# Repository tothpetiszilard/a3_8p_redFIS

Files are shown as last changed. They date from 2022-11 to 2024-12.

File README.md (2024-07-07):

# Audi A3 8P Red FIS Project
<b>This is a project about discovering (reverse-engineering) Audi A3 8P dashboard's Driver Information System and its protocol.</b>

For people who don't know what is DIS or FIS:
https://www.youtube.com/watch?v=bKFak5AGAGo

The goal is to implement a similiar but simpler open-source alternative to the "FIS-Control" or "Polar FIS".<br>
https://fis-control.de/index_en.html<br>
https://www.urotuning.com/products/polar-fis-advanced-multi-function-display-pf-04?variant=8384889323575

<b> Picture about the current status:</b><br>
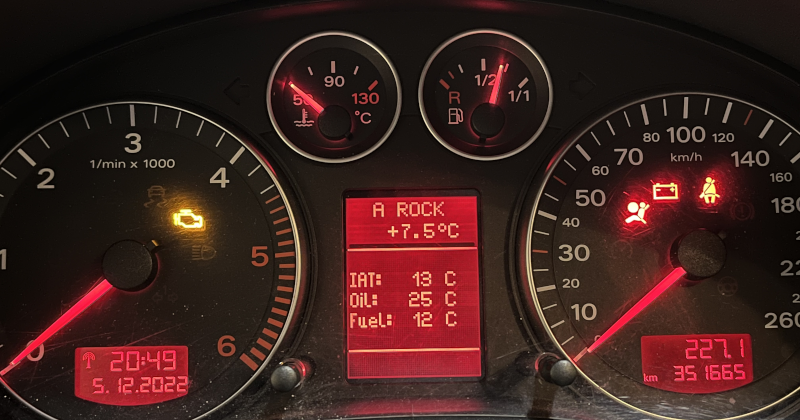
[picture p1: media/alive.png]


## Compatibility:
Selectable in "menuconfig":
- You can use Alternative VWTP CANID if you have RNS-E (Audi navigation with color display) installed and your dashboards part number is "8P0 920 930". Don't select "FIS-Control" in your RNS-E custom firmware in this case. Enter/exit FIS scenarios are a bit buggy.

- You have to use Navigation VWTP CANID if you have dashboard with part number "8P0 920 931". Alternative CANID is not supported by the dash. 

You may select "FIS-Control" in your RNS-E custom firmware in this case, and RedFIS will do the routing of the display data from RNS-E to the Dash - if that last "page" is selected using the Up/Down stalk buttons. This feature can be enabled (or disabled) in the menuconfig.
Default state is enabled, since my car has a navigation with custom firmware and "FIS-Control" option enabled.

<i>Brave volunteers are warmly welcomed for testing... :)</i>

Used and helpful sources:<br>
https://docs.google.com/spreadsheets/d/1eirT8LbSRl4j06BpwgsiE4PM_2BGH9UStdWLXwKvHJw/edit#gid=10<br>
https://i-wiki.tech/?post=vw-transport-protocol-20-tp-20-for-can-bus<br>
http://www.orlaus.dk/mercantec/UdvidetHardwareSoftware/Can/OBD2/VW%20Transport%20Protocol%202.0%20(TP%202.0)%20for%20CAN%20bus%20_%20jazdw.pdf<br>
https://github.com/openvehicles/Open-Vehicle-Monitoring-System-3/blob/master/vehicle/OVMS.V3/components/vehicle/docs/VW-TP-2.0.txt<br>

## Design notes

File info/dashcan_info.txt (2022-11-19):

CAN frames on the bus where the Dashboard is connected:

ID: 470 DLC: 5 [0][1][2][3][4]
byte 0: 128 = battery symbol shown
byte 1: doors: 1 = FL, 2 = FR,4= RL, 8 = RR, 16 = hood, 32 = trunk
byte 2: backlight dimming
byte 3: unknown
byte 4: 64 = light sensor error

ID: 1A0 DLC: 8 [0][1][2][3][4][5][6][7]
byte 1: errors, 1 = abs,2 = esp
byte 7: systick, 10ms increments

ID: 531 DLC: 4 [0][1][2][3]
byte 0: lamps: 4 = high beam
byte 1: symbols: 4 = green arrows
byte 2: turn signals: 1=left,2=right
byte 3: unknown

ID: 2A0 DLC: 8 [0][1][2][3][4][5][6][7]
byte 3: 1 = tire pressure monitoring error

ID: 3D0 DLC: 6 [0][1][2][3][4][5]
byte 1: 1 = steering error symbol

ID: 480 DLC: 8 [0][1][2][3][4][5][6][7]
byte 1: errors: 2=preglow,8=engine,16=coolant

ID: 280 DLC: 8 [0][1][rpm][rpm][4][5][6][7]
byte 2: LSB of engine speed?
byte 3: MSB of engine speed

ID: 661 DLC: 8 [FIS][?][?][?][?][?][?][?]
byte 0: FIS: 1 = ON

ID: 595 DLC: 3 [0][1][?] // trailer
byte 0: trailer light failures: brake=1,fog=2,reverse=4
byte 1: trailer light failures: right_turn=4,right_rear_light=8,left_turn=64,left_rear_light=128 

ID: 575 DLC:4 [ignition switch][1][2][3]
byte 0: ignition switch: 2 = KL15

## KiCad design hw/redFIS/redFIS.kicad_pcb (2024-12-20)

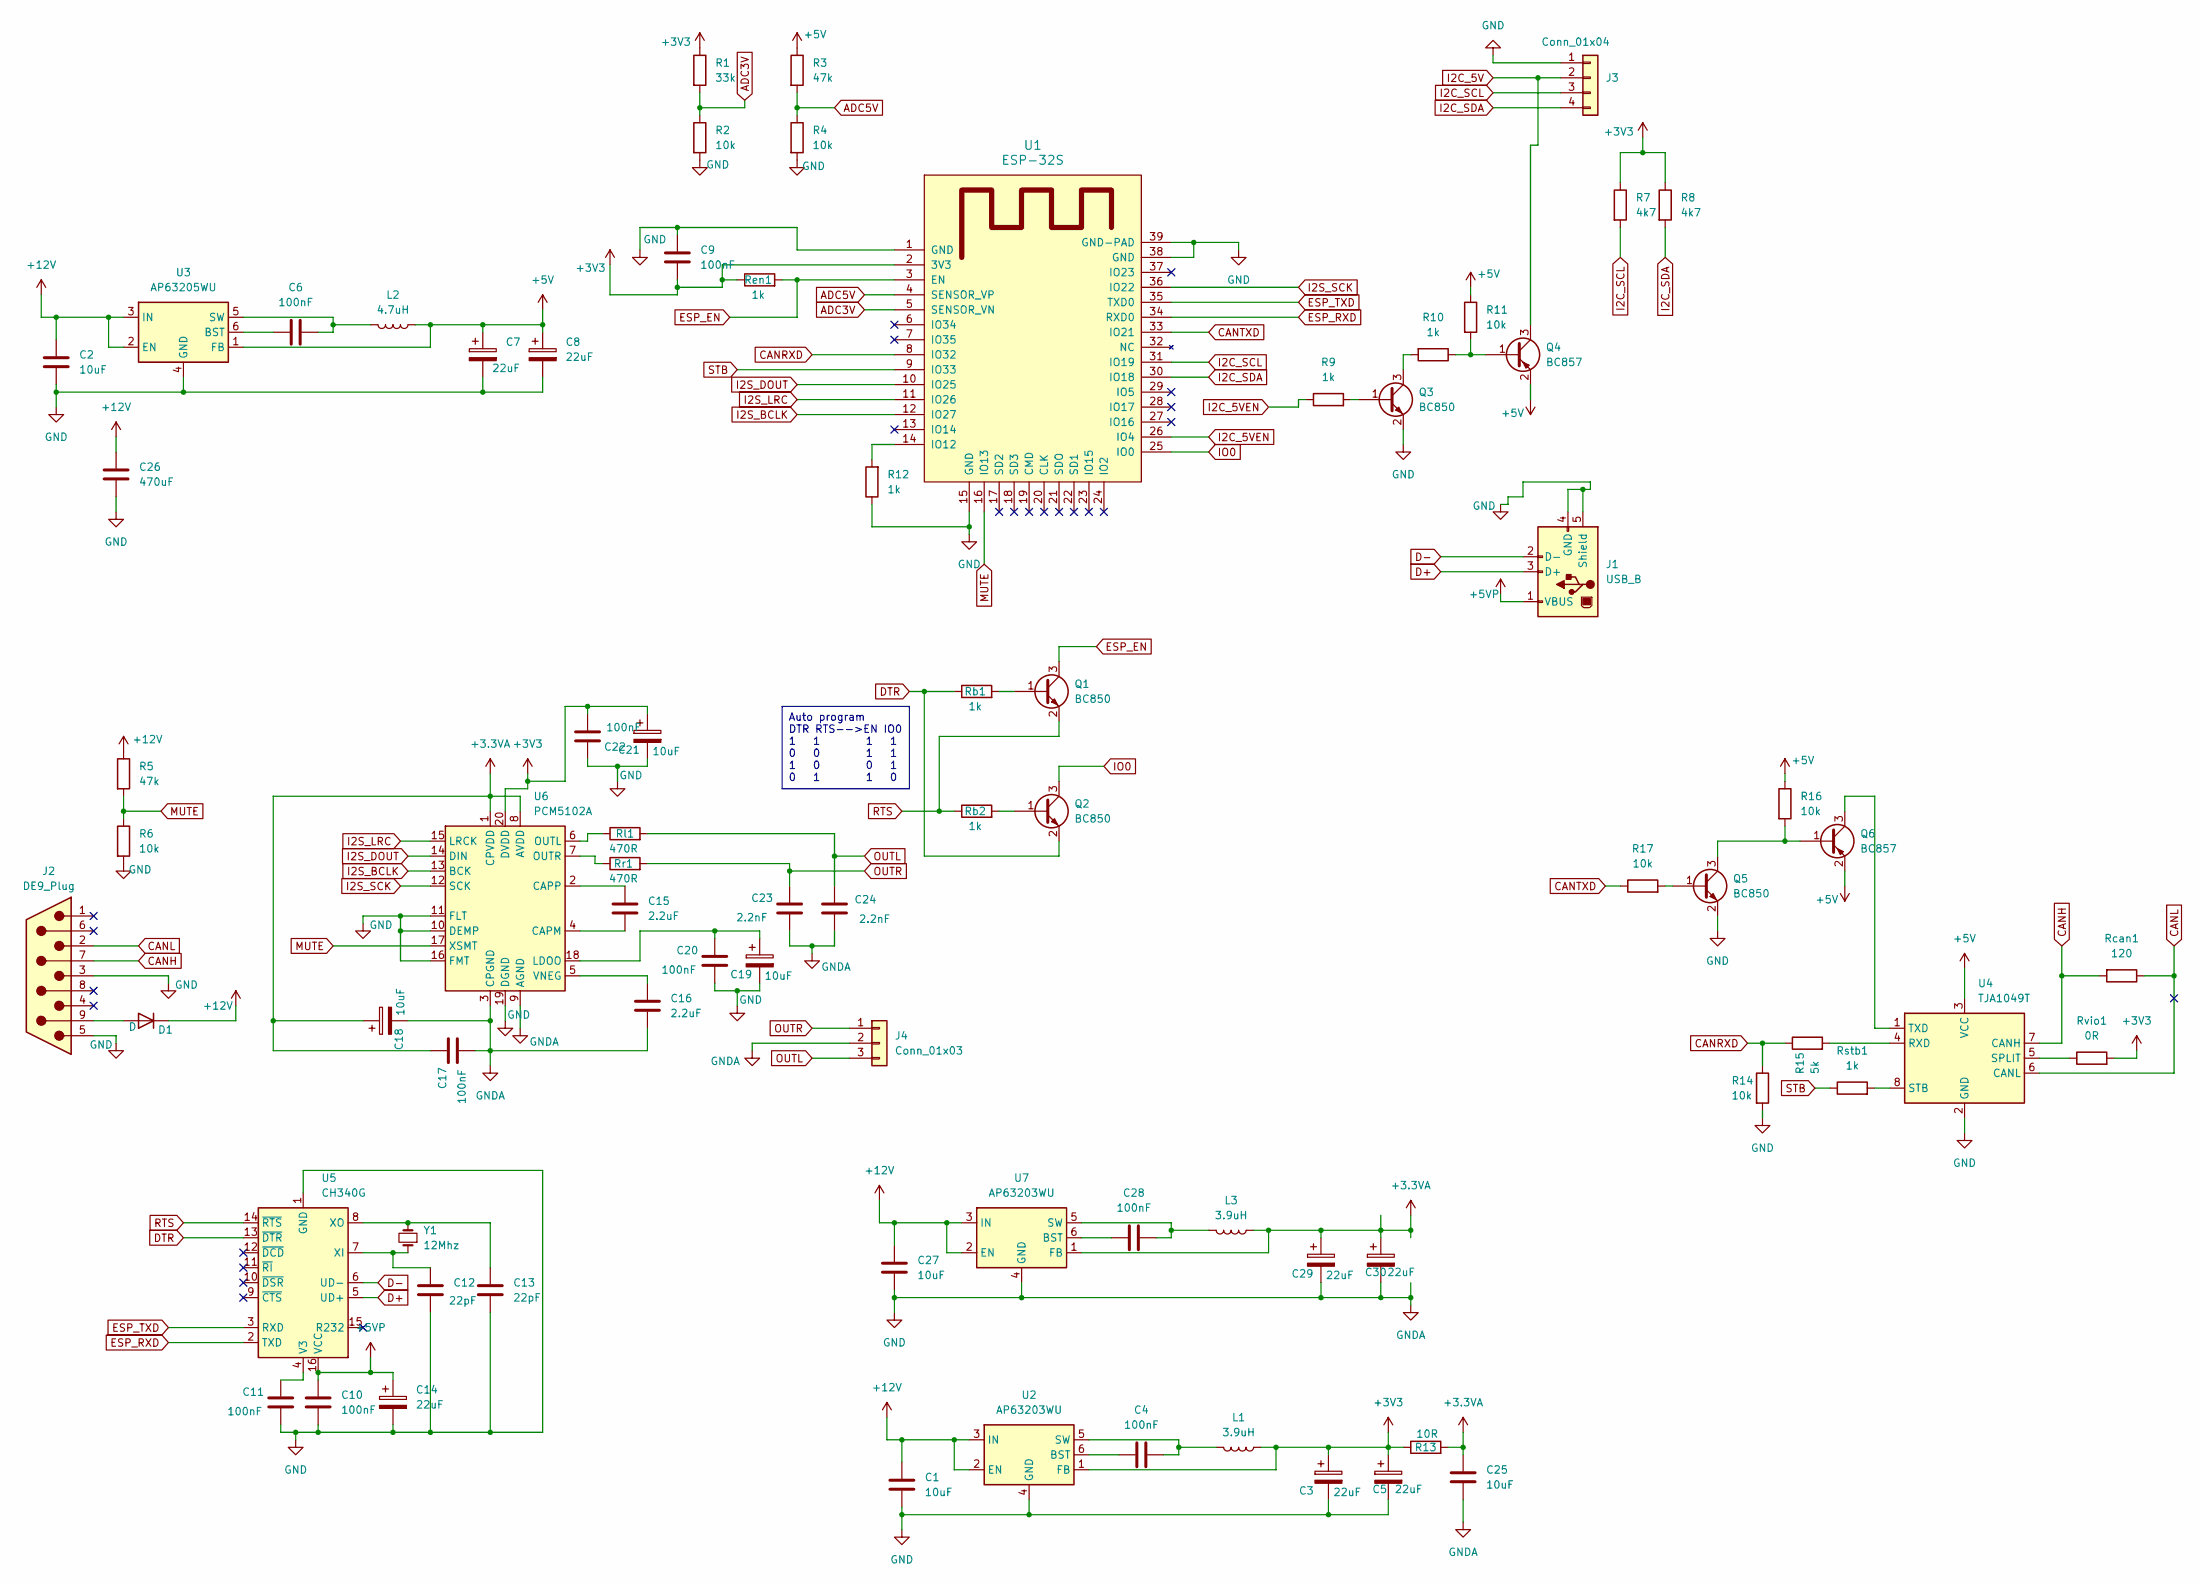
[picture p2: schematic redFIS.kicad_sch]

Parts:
C1, C2, C18, C19, C21, C25, C27: 10uF; C_0603_1608Metric_Pad1.08x0.95mm_HandSolder
C3, C5, C7, C8, C14, C29, C30: 22uF; C_1210_3225Metric_Pad1.33x2.70mm_HandSolder
C4, C6, C9, C10, C11, C17, C20, C22, C28: 100nF; C_0603_1608Metric_Pad1.08x0.95mm_HandSolder
C12, C13: 22pF; C_0603_1608Metric_Pad1.08x0.95mm_HandSolder
C15, C16: 2.2uF; C_0603_1608Metric_Pad1.08x0.95mm_HandSolder
C23, C24: 2.2nF; C_0603_1608Metric_Pad1.08x0.95mm_HandSolder
C26: 470uF; CP_Radial_D16.0mm_P7.50mm
D1: D; D_SMB_Handsoldering
J1: USB_B; USB_B_OST_USB-B1HSxx_Horizontal
J2: DE9_Plug; DSUB-9_Male_EdgeMount_P2.77mm
J3: Conn_01x04; PinHeader_1x04_P2.54mm_Vertical
J4: Conn_01x03; PinHeader_1x03_P2.54mm_Vertical
L1, L3: 3.9uH; L_TracoPower_TCK-047_5.2x5.8mm
L2: 4.7uH; L_TracoPower_TCK-047_5.2x5.8mm
Q1, Q2: BC850; SOT-23_Handsoldering
Q3, Q5: BC850; SOT-23
Q4, Q6: BC857; SOT-23
R1: 33k; R_0603_1608Metric_Pad0.98x0.95mm_HandSolder
R2, R4, R6, R11, R14, R16, R17: 10k; R_0603_1608Metric_Pad0.98x0.95mm_HandSolder
R3, R5: 47k; R_0603_1608Metric_Pad0.98x0.95mm_HandSolder
R7, R8: 4k7; R_0603_1608Metric_Pad0.98x0.95mm_HandSolder
R9, R10, R12: 1k; R_0603_1608Metric_Pad0.98x0.95mm_HandSolder
R13: 10R; R_1206_3216Metric_Pad1.30x1.75mm_HandSolder
R15: 5k; R_0603_1608Metric_Pad0.98x0.95mm_HandSolder
Rb1, Rb2: 1k; R_0603_1608Metric_Pad0.98x0.95mm_HandSolder
Rcan1: 120; R_0603_1608Metric_Pad0.98x0.95mm_HandSolder
Ren1: 1k; R_0603_1608Metric_Pad0.98x0.95mm_HandSolder
Rl1: 470R; R_0603_1608Metric_Pad0.98x0.95mm_HandSolder
Rr1: 470R; R_0603_1608Metric_Pad0.98x0.95mm_HandSolder
Rstb1: 1k; R_0603_1608Metric_Pad0.98x0.95mm_HandSolder
Rvio1: 0R; R_0603_1608Metric_Pad0.98x0.95mm_HandSolder
U1: ESP-32S
U2, U7: AP63203WU; TSOT-23-6
U3: AP63205WU; TSOT-23-6
U4: TJA1049T; SOIC-8_3.9x4.9mm_P1.27mm
U5: CH340G; SOIC-16_3.9x9.9mm_P1.27mm
U6: PCM5102A; TSSOP-20_4.4x6.5mm_P0.65mm
Y1: 12Mhz; Crystal_SMD_HC49-SD_HandSoldering

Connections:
+3.3VA: C17.2, C18.1, C25.1, C29.1, C30.1, L3.1, R13.2, U6.1 (CPVDD), U6.8 (AVDD), U7.1 (FB)
+3V3: C3.1, C5.1, C9.1, C21.1, C22.1, L1.1, R1.1, R7.1, R8.1, R13.1, Ren1.1, Rvio1.2, U1.2 (3V3), U2.1 (FB), U6.20 (DVDD)
+5V: C7.1, C8.1, L2.1, Q4.2 (E), Q6.2 (E), R3.1, R11.1, R16.1, U3.1 (FB), U4.3 (VCC)
+5VP: C10.2, C14.1, J1.1 (VBUS), U5.16 (VCC)
+12V: C1.1, C2.1, C26.1, C27.1, D1.1 (K), R5.1, U2.2 (EN), U2.3 (IN), U3.2 (EN), U3.3 (IN), U7.2 (EN), U7.3 (IN)
ADC3V: R1.2, R2.1, U1.5 (SENSOR_VN)
ADC5V: R3.2, R4.1, U1.4 (SENSOR_VP)
CANH: J2.7, Rcan1.2, U4.7 (CANH)
CANL: J2.2, Rcan1.1, U4.6 (CANL)
CANRXD: R14.1, R15.1, U1.8 (IO32)
CANTXD: R17.1, U1.33 (IO21)
D+: J1.3 (D+), U5.5 (UD+)
D-: J1.2 (D-), U5.6 (UD-)
DTR: Q2.2 (E), Rb1.1, U5.13 (~DTR)
ESP_EN: Q1.3 (C), Ren1.2, U1.3 (EN)
ESP_RXD: U1.34 (RXD0), U5.2 (TXD)
ESP_TXD: U1.35 (TXD0), U5.3 (RXD)
GND: C1.2, C2.2, C3.2, C5.2, C7.2, C8.2, C9.2, C10.1, C11.1, C12.1, C13.1, C14.2, C16.2, C17.1, C18.2, C19.2, C20.1, C21.2, C22.2, C23.1, C24.1, C25.2, C26.2, C27.2, C29.2, C30.2, J1.4 (GND), J1.5 (Shield), J2.3, J2.5, J3.1, J4.2, Q3.2 (E), Q5.2 (E), R2.2, R4.2, R6.2, R12.1, R14.2, U1.1 (GND), U1.15 (GND), U1.38 (GND), U1.39 (GND-PAD), U2.4 (GND), U3.4 (GND), U4.2 (GND), U5.1 (GND), U6.3 (CPGND), U6.9 (AGND), U6.10 (DEMP), U6.11 (FLT), U6.16 (FMT), U6.19 (DGND), U7.4 (GND)
I2C_5V: J3.2, Q4.3 (C)
I2C_5VEN: R9.1, U1.26 (IO4)
I2C_SCL: J3.3, R7.2, U1.31 (IO19)
I2C_SDA: J3.4, R8.2, U1.30 (IO18)
I2S_BCLK: U1.12 (IO27), U6.13 (BCK)
I2S_DOUT: U1.10 (IO25), U6.14 (DIN)
I2S_LRC: U1.11 (IO26), U6.15 (LRCK)
I2S_SCK: U1.36 (IO22), U6.12 (SCK)
IO0: Q2.3 (C), U1.25 (IO0)
MUTE: R5.2, R6.1, U1.16 (IO13), U6.17 (XSMT)
unnamed: D1.2 (A), J2.9
unnamed: Q1.1 (B), Rb1.2
unnamed: Q2.1 (B), Rb2.2
unnamed: Q3.1 (B), R9.2
unnamed: Q3.3 (C), R10.2
unnamed: Q4.1 (B), R10.1, R11.2
unnamed: Q5.1 (B), R17.2
unnamed: Q5.3 (C), Q6.1 (B), R16.2
unnamed: Q6.3 (C), U4.1 (TXD)
unnamed: R12.2, U1.14 (IO12)
unnamed: C4.1, U2.6 (BST)
unnamed: C4.2, L1.2, U2.5 (SW)
unnamed: C6.1, U3.6 (BST)
unnamed: C6.2, L2.2, U3.5 (SW)
unnamed: R15.2, U4.4 (RXD)
unnamed: Rvio1.1, U4.5 (SPLIT)
unnamed: Rstb1.2, U4.8 (STB)
unnamed: C11.2, U5.4 (V3)
unnamed: C12.2, U5.7 (XI), Y1.1
unnamed: C13.2, U5.8 (XO), Y1.2
unnamed: C15.2, U6.4 (CAPM)
unnamed: C15.1, U6.2 (CAPP)
unnamed: C19.1, C20.2, U6.18 (LDOO)
unnamed: Rl1.1, U6.6 (OUTL)
unnamed: Rr1.1, U6.7 (OUTR)
unnamed: C16.1, U6.5 (VNEG)
unnamed: C28.1, U7.6 (BST)
unnamed: C28.2, L3.2, U7.5 (SW)
OUTL: C24.2, J4.3, Rl1.2
OUTR: C23.2, J4.1, Rr1.2
RTS: Q1.2 (E), Rb2.1, U5.14 (~RTS)
STB: Rstb1.1, U1.9 (IO33)

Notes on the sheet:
Auto program DTR RTS-->EN IO0 1 1 1 1 0 0 1 1 1 0 0 1 0 1 1 0

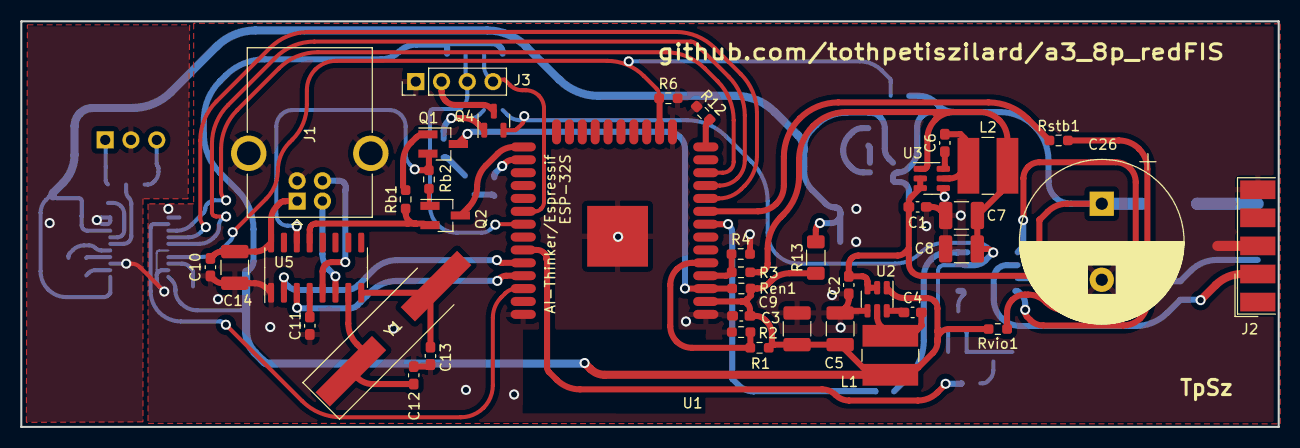
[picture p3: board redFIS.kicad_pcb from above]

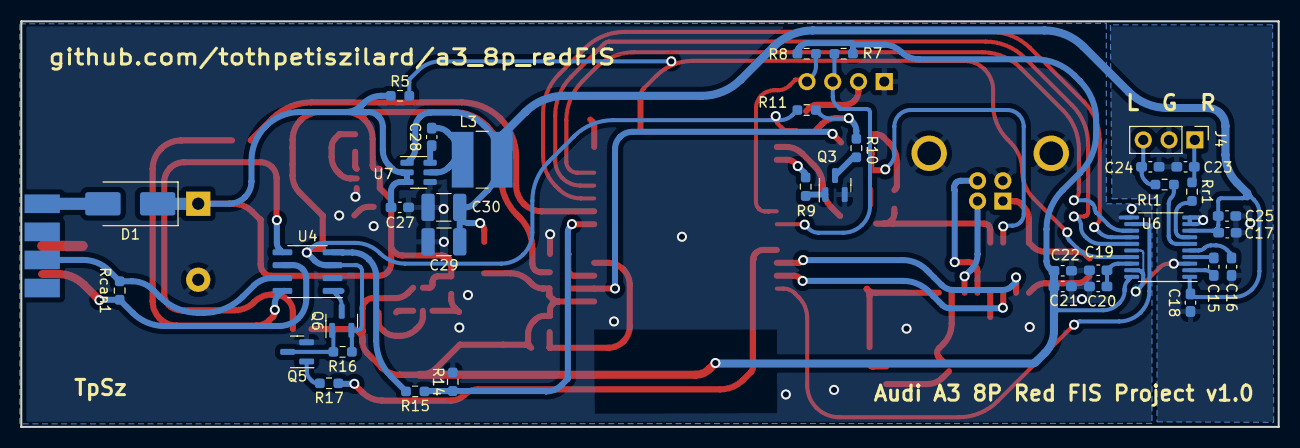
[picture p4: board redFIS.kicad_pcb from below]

Board: 2 copper layers, 124.0 x 40.0 mm, 77 parts (37 on the bottom side), 60 nets.

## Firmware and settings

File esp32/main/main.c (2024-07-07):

/* A3 8P Red FIS project 2023 */
#include "freertos/FreeRTOS.h"
#include "freertos/task.h"
#include "esp_sleep.h"
#include "canWrapper.h"
#include "vwtp.h"
#include "dashapp.h"
#include "navapp.h"
#include "dis.h"
#include "enginediag.h"
#include "kwp.h"
#ifdef REDFIS_SINGLE_THREAD
#include "esp_task_wdt.h"
#endif

void app_main()
{
    #ifdef REDFIS_SINGLE_THREAD
    static uint64_t last10, last50, last100, last300;
    uint64_t sysTime;
    #endif
    esp_sleep_wakeup_cause_t wakeup_reason;

    wakeup_reason = esp_sleep_get_wakeup_cause();
    switch(wakeup_reason)
    {
        case ESP_SLEEP_WAKEUP_EXT0 : printf("Wakeup caused by external signal using RTC_IO\n"); break;
        case ESP_SLEEP_WAKEUP_EXT1 : printf("Wakeup caused by external signal using RTC_CNTL\n"); break;
        case ESP_SLEEP_WAKEUP_TIMER : printf("Wakeup caused by timer\n"); break;
        case ESP_SLEEP_WAKEUP_TOUCHPAD : printf("Wakeup caused by touchpad\n"); break;
        case ESP_SLEEP_WAKEUP_ULP : printf("Wakeup caused by ULP program\n"); break;
        default : printf("Wakeup was not caused by deep sleep: %d\n",wakeup_reason); break;
    }

    Can_Init();
    VwTp_Init();
    DashApp_Init();
    NavApp_Init();
    Dis_Init();
    #ifdef REDFIS_SINGLE_THREAD
    esp_task_wdt_add(NULL);
    while(1)
    {
        sysTime = xTaskGetTickCount() * portTICK_PERIOD_MS;
        Can_Receive(NULL);
        esp_task_wdt_reset();
        if (sysTime >= last10 + 10u)
        {
            last10 = sysTime;
            VwTp_Cyclic(NULL);
        }
        if (sysTime >= last50 + 50u)
        {
            last50 = sysTime;
            Kwp_Cyclic(NULL);
            DashApp_Cyclic(NULL);
        }
        if (sysTime >= last100 + 100u)
        {
            last100 = sysTime;
            EngineDiag_Cyclic(NULL);
        }
        if (sysTime >= last300 + 300u)
        {
            last300 = sysTime;
            Dis_Cyclic(NULL);
        }
    }
    #else
    vTaskDelete(NULL);
    #endif
}

 

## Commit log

2022-11-24 First running 'demo' version on ESP32 hw, no real functionality yet, just a feasibility study
2022-11-24 Bugfixes: VWTP: Resend + wait for ack; DashApp: switched to small font as the comment says
2022-11-24 Configured CAN acceptance filter
2022-11-24 Added support for stalk buttons
2022-12-14 Single-thread version of the software for testing purposes
2022-12-23 Update canWrapper.c
    Fixing a huge but well hidden bug. CAN of course shall resend the frame if it lost the arbitration ...
2022-12-24 Added page switching to DIS
2023-03-22 Added ignition detection to DashApp and KWP, adapted can filter, did some changes on DIS
2023-12-21 Undate code to v0_2, unstable version
    [main.c]
2023-12-25 Small fixes in the 'old' code
    [main.c]
2024-07-04 Bugfix for switching between diag and nav routing screens
2024-12-15 Started HW design in KiCAD
    [redFIS.kicad_pcb, redFIS.kicad_sch]
2024-12-15 Changes in schematic
    [redFIS.kicad_sch]
2024-12-17 Worked on HW design - layout
    [redFIS.kicad_pcb, redFIS.kicad_sch]
2024-12-19 Finished first version of PCB
    [redFIS.kicad_pcb, redFIS.kicad_sch]
2024-12-20 HW design bugfix
    [redFIS.kicad_pcb, redFIS.kicad_sch]
2024-12-20 Finished bugfixing of HW design v1
    [redFIS.kicad_pcb]
2024-12-20 PCB update - Almost forget to round the tracks...
    [redFIS.kicad_pcb]
2024-12-20 PCB - Label movement on silkscreen
    [redFIS.kicad_pcb]
